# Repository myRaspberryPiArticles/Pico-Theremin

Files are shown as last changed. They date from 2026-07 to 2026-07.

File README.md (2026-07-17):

# Pico-Theremin
My version of a theremin, built with a Raspberry Pi Pico, buzzer and Time of Flight sensors! See the code, detailed description, parts list and things you will need to build it here!

## Pictures

F1972FA2-C316-47A3-9ECE-AAF5E4CAD924_4_5005_c
C410DEB3-3112-4E5E-9E45-270C67D85610_4_5005_c
AA3081A0-54C1-49CB-B78B-664D1BF1BF9E_4_5005_c
458DC4B5-77CA-4C18-B4D9-B085813C253E_4_5005_c
3CAB9EA3-80EF-45F4-9CAF-A3239A417DEA_4_5005_c

## What it is

A theremin is a simple device that allows hand gestures and movements to be transmitted into sound, with different frequencies and volumes based on the movements. They usually have two metal rods that create an electromagnetic field to detect hand movements. 

My version of this is built with 2 Time of Flight sensors that get hand input, and a buzzer that outputs the sound. I also added a small OLED, which can display the sound wave it is producing, using some math implemented in the code. It changes the wave length and wave width on the screen to visualise the sound.

You can see a working model of it here: [https://www.youtube.com/shorts/vbbmoebM0_U](https://www.youtube.com/shorts/vbbmoebM0_U)

## How it works

The two sensors each detect two different distances the hand is, and they are used to become a buzzer’s frequency and amplitude. The code gives out a value in millimetres, anywhere from 5 to 600 - while the buzzer requires a sound of 36 - 1024 Hz. To make this achievable, we multiply the distance readings by 10 for the pitch. However, the buzzer duty cycle (volume) ranges anywhere from 0 (silent); 32768 (50%) and 65534 (loudest). To match the integer it requires, we multiply the volume reading by 40. The main processing chip is a Raspberry Pi Pico, and it is a small maker board for these types of projects. To control the volume of the buzzer, it has PWM GPIO pins, which stand for Pulse Width Modulation General Purpose Input/Output pins. They basically make the flow of electricity go on and off at different speeds to make the buzzer louder or quieter.

## Code

The code is split up into 2 codes, one that controls sensors, and one that is the main.py where the OLED is run. You do need to download the 'vl53l0x' library to get the sensors to work properly, and when wiring remember to put the sensors on DIFFERENT I2C BUSES. I found a small I2C scan code to be helpful when testing.

## Case design



I printed a simple bumper for my Theremin to keep the wiring on the bottom safe. I designed it in TinkerCAD, in a way that my protoboard it is built on can sit inside it. The STL files are above for you to download for yourelf!

<br clear="left"/>

## Parts List

| Part | Where to buy |
| :--- | :---: |
| Raspberry Pi Pico | [PiHut](https://thepihut.com/products/raspberry-pi-pico?variant=41925332566211) |
| x2 Time of Flight sensors | [Amazon](https://www.amazon.com/ALAMSCN-Breakout-VL53L0XV2-Distance-Measurement/dp/B08V8SKKZ4) |
| Passive buzzer (make sure it changes sound) | [Amazon](https://www.amazon.co.uk/sourcing-map-Passive-Electronic-Electromagnetic/dp/B08MDNL2DW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) |
| 0.91" OLED | [Amazon](https://www.amazon.co.uk/DollaTek-Display-SSD1306-3-3V-5V-Arduino/dp/B07MHGPNVT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) |

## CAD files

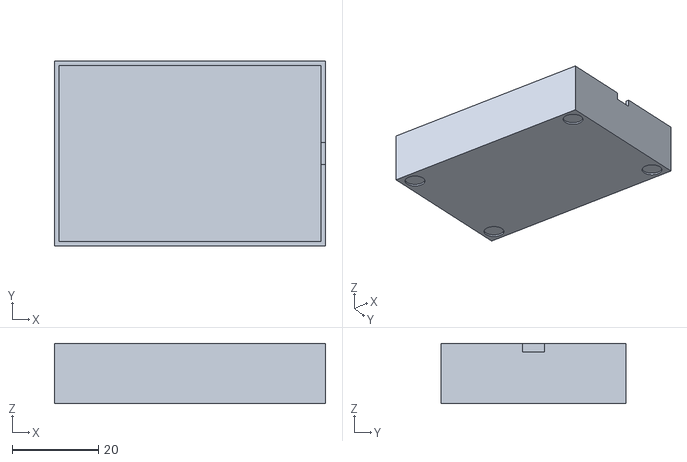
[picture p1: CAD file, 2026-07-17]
Case/case.stl
63.0 x 43.0 x 14.0

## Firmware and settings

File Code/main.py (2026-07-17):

import time
import math
from machine import Pin, I2C, SoftI2C, PWM
import ssd1306
from vl53l0x import VL53L0X

# =========================================================
# STEP 1: INITIALIZE HARDWARE (Pins & Audio)
# =========================================================
# Power up the sensors via XSHUT pins
Pin(15, Pin.OUT).value(1)
Pin(14, Pin.OUT).value(1)
time.sleep(0.2) 

# Audio Setup
buzzer = PWM(Pin(5))
led = Pin("LED", Pin.OUT)
led.value(1)

# =========================================================
# STEP 2: INITIALIZE I2C BUSES (No overlapping hardware blocks)
# =========================================================
# Bus 1 (Pins 10/11) - Pitch Sensor (Hardware I2C)
i2c1 = I2C(1, sda=Pin(10), scl=Pin(11), freq=400000)

# Bus 0 (Pins 8/9) - Volume Sensor (Hardware I2C)
i2c0 = I2C(0, sda=Pin(8),  scl=Pin(9),  freq=400000)

# Pins 2/3 - OLED Display (Using SoftI2C to avoid hijacking Hardware I2C 1)
i2c_oled = SoftI2C(sda=Pin(2), scl=Pin(3), freq=400000)

print("Bus 1 Scan (Pitch):", i2c1.scan()) 
print("Bus 0 Scan (Volume):", i2c0.scan()) 
print("OLED Bus Scan:", i2c_oled.scan())

# Initialize ToF Sensors
tof_pitch = VL53L0X(i2c1, address=41)  
tof_vol   = VL53L0X(i2c0, address=41)  

# Initialize OLED (128x32 screen size)
oled = ssd1306.SSD1306_I2C(128, 32, i2c_oled)

# =========================================================
# STEP 3: SETUP VARIABLES & FILTERS
# =========================================================
tof_pitch.set_measurement_timing_budget(40000)
tof_vol.set_measurement_timing_budget(40000)

n = 15
pitch_group = []
vol_group = []
avg_pitch = 0
avg_vol = 0

# Place this in STEP 3 of your script
smoothed_vol_duty = 0.0  # Tracks the actual current volume for smooth gliding

# Oscilloscope Animation variables (Adjusted for 32px height)
phase_shift = 0
center_y = 16  # Changed from 32 to 16 so the wave sits perfectly in the middle

print("🎛️ Theremin + Oscilloscope Active!")

# =========================================================
# STEP 4: THE UNIFIED, NON-BLOCKING LOOP
# =========================================================

while True:
    try:
        # --- 1. READ SENSORS ---
        raw_pitch = tof_pitch.ping() - 50
        raw_vol = tof_vol.ping() - 75
        
        # --- 2. FILTER DATA ---
        if raw_pitch not in (8140, 8141) and raw_pitch > 0:
            pitch_group.append(raw_pitch)
            if len(pitch_group) > n: pitch_group.pop(0)
            avg_pitch = int(sum(pitch_group) / len(pitch_group))
            
        if raw_vol not in (8140, 8141) and raw_vol > 0:
            vol_group.append(raw_vol)
            if len(vol_group) > n: vol_group.pop(0)
            avg_vol = int(sum(vol_group) / len(vol_group))
            
        # --- 3. AUDIO MAPPING & EXECUTION ---
        # A. Map pitch (Distance -> Frequency)
        pitch_freq = 100 + int(avg_pitch * 1.5)
        pitch_freq = max(40, min(pitch_freq, 1000)) 
        buzzer.freq(pitch_freq)
        
        # B. Map volume using a quadratic curve (avoids sudden quiet-to-loud jumps)
        # Normalize distance to a 0.0 - 1.0 scale (assuming max comfortable distance ~400mm)
        norm_vol = min(max(avg_vol / 400.0, 0.0), 1.0)
        
        # Squaring it (norm_vol * norm_vol) creates a smooth exponential curve for your ear
        target_volume_duty = int((norm_vol ** 2) * 32768) 
        
        # C. Apply the Glide Filter (Exponential Moving Average)
        # 0.10 means the volume moves 10% closer to your hand's position every single frame.
        # Lower = smoother/slacker glide. Higher (e.g., 0.25) = faster/snappier response.
        smoothing_factor = 0.10 
        smoothed_vol_duty += (target_volume_duty - smoothed_vol_duty) * smoothing_factor
        
        # Send the final smoothed value to the hardware
        buzzer.duty_u16(int(smoothed_vol_duty))
        
        # --- 4. VISUAL MAPPING (DYNAMIC OSCILLOSCOPE) ---
        wave_frequency = 0.05 + (1.0 / (avg_pitch + 1)) * 20 
        wave_frequency = max(0.05, min(wave_frequency, 0.4))

        # Scale down max amplitude to 12 pixels so it doesn't clip off the 32px screen bounds
        # Map Volume to Wave Amplitude using the newly smoothed volume duty cycle
        wave_amplitude = int((smoothed_vol_duty / 32768) * 12)        
        # --- 5. RENDER OLED FRAME ---
        oled.fill(0) 
        
        # Plot and draw the wave
        last_x = 0
        last_y = int(center_y + math.sin((last_x * wave_frequency) + phase_shift) * wave_amplitude)
        
        for x in range(1, 128):
            y = int(center_y + math.sin((x * wave_frequency) + phase_shift) * wave_amplitude)
            oled.line(last_x, last_y, x, y, 1) 
            last_x = x
            last_y = y
            
        oled.show() 
        phase_shift -= 0.25
        
    except OSError as e:
        print(f"I2C Bus Glitch Caught: {e}")
        oled.text("ERROR with I2C", 0, 16)
        buzzer.duty_u16(0)
        
    time.sleep_ms(2)

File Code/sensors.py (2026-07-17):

import time
from machine import Pin, I2C, PWM
from vl53l0x import VL53L0X

# 1. Wake up the sensor (XSHUT must be HIGH)
xshut = Pin(14, Pin.OUT)  # or 15 or 14
xshut.value(1)
time.sleep_ms(200)

xshut1 = Pin(15, Pin.OUT)  # or 15 or 14
xshut1.value(1)
time.sleep_ms(200)

time.sleep(2)

buzzer = PWM(Pin(5))

print("Setting up I2C")
sda = Pin(10) #or 10 or 8
scl = Pin(11) #or 11 or 9

sda1 = Pin(8) #or 10 or 8
scl1 = Pin(9) #or 11 or 9
# Explicit frequency prevents init handshake failures
# Lower frequency to 100kHz to prevent clock-stretching EIO errors
i2c1 = I2C(id=1, sda=sda, scl=scl, freq=100000) #or id 1 for 10/11 or id 0 for8/9
i2c0 = I2C(id=0, sda=sda1, scl=scl1, freq=100000)
print("I2C Scan:", i2c1.scan())  # Should return [41]
print("I2C Scan:", i2c0.scan())

print("Creating VL53L0X object...")
tof = VL53L0X(i2c1)
tof1 = VL53L0X(i2c0)

budget = tof.measurement_timing_budget_us
print("Budget was:", budget)
tof.set_measurement_timing_budget(100000)

budget1 = tof1.measurement_timing_budget_us
print("Budget was:", budget1)
tof1.set_measurement_timing_budget(100000)

# VCSEL pulse periods
tof.set_Vcsel_pulse_period(tof.vcsel_period_type[0], 18)
tof.set_Vcsel_pulse_period(tof.vcsel_period_type[1], 14)

tof1.set_Vcsel_pulse_period(tof1.vcsel_period_type[0], 18)
tof1.set_Vcsel_pulse_period(tof1.vcsel_period_type[1], 14)


def play_tone(frequency, duration):
    """Plays a specific frequency for a set duration in seconds"""
    buzzer.freq(frequency)
    # 32768 is a 50% duty cycle, which gives max volume for a passive buzzer
    buzzer.duty_u16((avgToF1 * 10)) 
    time.sleep(duration)

n = 20
reading_group = []

n1 = 20
reading_group1 = []

# Initialize the average variables before the loop so they always exist
avg = 0.0
avg1 = 0.0

print("Starting measurements")

# Initialize your variables so they always exist at startup
avg = 0.0
avg1 = 0.0
avgToF = 0
avgToF1 = 0

print("Starting measurements...")

while True:
    try:
        new_value = tof.ping() - 50
        new_value1 = tof1.ping() - 75
        
        # Filter out error codes for Sensor 1 (Pitch)
        if new_value not in (8140, 8141):
            reading_group.append(new_value)
            if len(reading_group) > n:
                reading_group.pop(0)
            avg = sum(reading_group) / len(reading_group)
            avgToF = int(avg)
            
        # Filter out error codes for Sensor 2 (Volume)
        if new_value1 not in (8140, 8141):
            reading_group1.append(new_value1)
            if len(reading_group1) > n1:
                reading_group1.pop(0)
            avg1 = sum(reading_group1) / len(reading_group1)
            avgToF1 = int(avg1)
            
        # =========================================================
        # PITCH AND VOLUME CONTROL (Right next to each other!)
        # =========================================================
        
        # 1. Set Tone Pitch (Sensor 1)
        pitch = avgToF * 10
        if pitch < 20: pitch = 20  # Keep it above human hearing minimum
        buzzer.freq(pitch)
        
        # 2. Set Volume (Sensor 2)
        volume = avgToF1 * 40      # Simple multiplier just like the tone!
        if volume > 32768:         # Cap it at 32768 (50% duty cycle) for max volume
            volume = 32768         # This prevents the audio from cutting out or crashing
            
        buzzer.duty_u16(volume)
        # =========================================================
        
        print(f"Avg 1 (Pitch): {avg:.1f} mm  |  Avg 2 (Vol): {avg1:.1f} mm")
        
    except OSError as e:
        print(f"I2C Read Error: {e}")
        buzzer.duty_u16(0) # Mute on error
        
    time.sleep(0.01)

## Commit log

2026-07-17 Add sensor initialization and measurement logic
    Initialize and configure VL53L0X sensors with I2C, set up PWM buzzer, and implement measurement loop for pitch and volume control.
    [sensors.py]
2026-07-17 Rename 458DC4B5-77CA-4C18-B4D9-B085813C253E_4_5005_c.jpeg to Images/Top View powered on
2026-07-17 Rename C410DEB3-3112-4E5E-9E45-270C67D85610_4_5005_c.jpeg to Images/Close Up powered on
2026-07-17 Rename F1972FA2-C316-47A3-9ECE-AAF5E4CAD924_4_5005_c.jpeg to Images/Top view powered off
2026-07-17 Rename Tremendous Krunk-Snicket.stl to Case/case.stl
    [case.stl]
